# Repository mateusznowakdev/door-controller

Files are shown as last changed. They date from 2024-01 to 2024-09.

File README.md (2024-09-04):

Project description can be found on
[my website](https://mateusznowak.dev/projects/automatic-door-controller/).

User manual can be found in [docs](./docs/README.md) directory.

## Installing

(instructions for Linux)

1. Clone the repository.
    - `git clone --recurse-submodules https://github.com/mateusznowakdev/door-controller`
2. Download and flash CircuitPython 9.1.3 using the official instructions.
    - [Download](https://adafruit-circuit-python.s3.amazonaws.com/bin/raspberry_pi_pico/en_US/adafruit-circuitpython-raspberry_pi_pico-en_US-9.1.3.uf2)
3. Download mpy-cross binary to the `firmware` directory, rename it and make it
   executable.
    - [Download (amd64)](https://adafruit-circuit-python.s3.amazonaws.com/bin/mpy-cross/linux-amd64/mpy-cross-linux-amd64-9.1.3.static)
4. Build and upload the code to the CIRCUITPY drive
    - `cd firmware`
    - `./upload.sh`

## Language options

Can be changed by creating `settings.toml` file on the CIRCUITPY drive, with the
following content:

```toml
LANG = "pl"
```

Supported languages: `en`, `pl`

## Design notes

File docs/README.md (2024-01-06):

# Raspberry Pi Pico-based motor controller<br/>User manual

## 1. Overview



1. HD44780 LCD module
2. Contrast potentiometer
3. DS3231 Real Time Clock (RTC) + AT24LC32 EEPROM module
4. Raspberry Pi Pico microcontroller module
5. Button module - Left button
6. Button module - Right button
7. Button module - OK button
8. Programmable motor output signal
9. Power input / output, in the following order: 3V3, GND, 5V
10. Auto-reset jumper

### 1.1. Safe default settings

The RTC / EEPROM module is used to keep track of the current time and store user settings.

Automatic opening and closing will be temporarily disabled if the time setting is invalid. Open time settings and set the current time again. Replace the battery if the problem is not resolved.

If EEPROM contents cannot be read due to the bad checksum, the default settings will be used:

- run from 00:00 to 00:00 for 0 seconds divided by 1

### 1.2. Auto-reset feature

This device is automatically reset after failure, such as lost communication with the real time clock module. LCD and button modules are not monitored.

This feature can be disabled if access to the USB serial console is required. Remove the jumper (10.) only if requested by qualified personnel.

## 2. User menu

### 2.1. Using the button module

The three buttons of the button module are used in the user menu, and produce different results in one of two modes:

| | Left | Right | OK |
|---|---|---|---|
|  <br/> **In the menu (cursor mode)**  | Press to move the cursor left. | Press to move the cursor right. | Press to select a highlighted option. This will invoke an action, enter a sub-menu or switch to editing mode. |
|  <br/> **In the menu (editing mode)** | Press to decrease the value by 1. Press and hold to do it faster. | Press to increase the value by 1. Press and hold to do it faster. | Press to confirm the value you have entered and return to cursor mode. |

The button module may stop working temporarily in the following conditions:

- Ongoing opening or closing operation
- Hardware failure

### 2.2. Idle screen



The following information is displayed on the idle screen:

| Icon | Description |
|---|---|
| &nbsp; | Current time |
|  | Automatic reset is disabled |
|  | System time is invalid |

Press and hold the **Left** button for a few seconds to enter the main menu.

### 2.3. Main menu



The following menu options are available:

| Icon | Description |
|---|---|
|  | Show scheduled operations |
|  | Open now (single operation according to the schedule)  |
|  | Close now (single operation according to the schedule) |
|  | Change opening parameters |
|   | Change closing parameters |
|  | Change system time |
|  | Show operation history |
|  | Return to the idle screen |

"Open" and "Close" operations requested from the main menu are run synchronously at the best precision possible, which means these cannot be stopped prematurely.

### 2.4. "Preview" menu



This menu is used to list all scheduled operations and their directions. Press the **Left** or **Right** button to switch to the previous or next page, respectively, or the **OK** button to return to the main menu.

If no operations are scheduled or if the system time is invalid, the following empty screen is shown:



### 2.5. "History" menu



This menu is similar to the preview menu but is used to list important events in the past, such as:

- device status
- opening and closing operations
- changed settings

Some log entries have an extra context:

| Icon | Description |
|---|---|
|  | Single (manual) |
|  | Automatic |
|  | Measurement |

### 2.6. "Set opening" and "Set closing" menus



These menus are used to change the parameters of the scheduled opening and closing operations. The following parameters can be set:

- Time of the first operation in the series
- Time of the last operation in the series
- Total duration for all operations in series during a day
- Number of operations during a day

The following actions are also available:

| Icon | Description |
|---|---|
|  | Start automatic measurement. See "2.6.1. Measurement menu" |
|  | Save the updated settings, then return to the main menu |
|  | Ignore the updated settings, then return to the main menu  |

**Example**: This example configuration will turn on the motor for approximately 10 seconds at 08:00, 09:00, ..., 15:00, and 16:00 every
day.

It might be necessary to fine-tune these values according to the weather conditions and motor parameters.

To disable opening or closing operations, set the total duration to 0s.

#### 2.6.1. Measurement menu



This sub-menu is used to run an opening or closing operation for an unspecified amount of time, usually for measurement purposes.

The opening or closing operation is run asynchronously, which means it can be stopped by pressing the **OK** button at the cost of worse precision. The displayed value is then set as a total duration in the "Set opening" or "Set closing" menu.

### 2.7. "Set clock" menu



This menu is used to change the system time to the specified value.

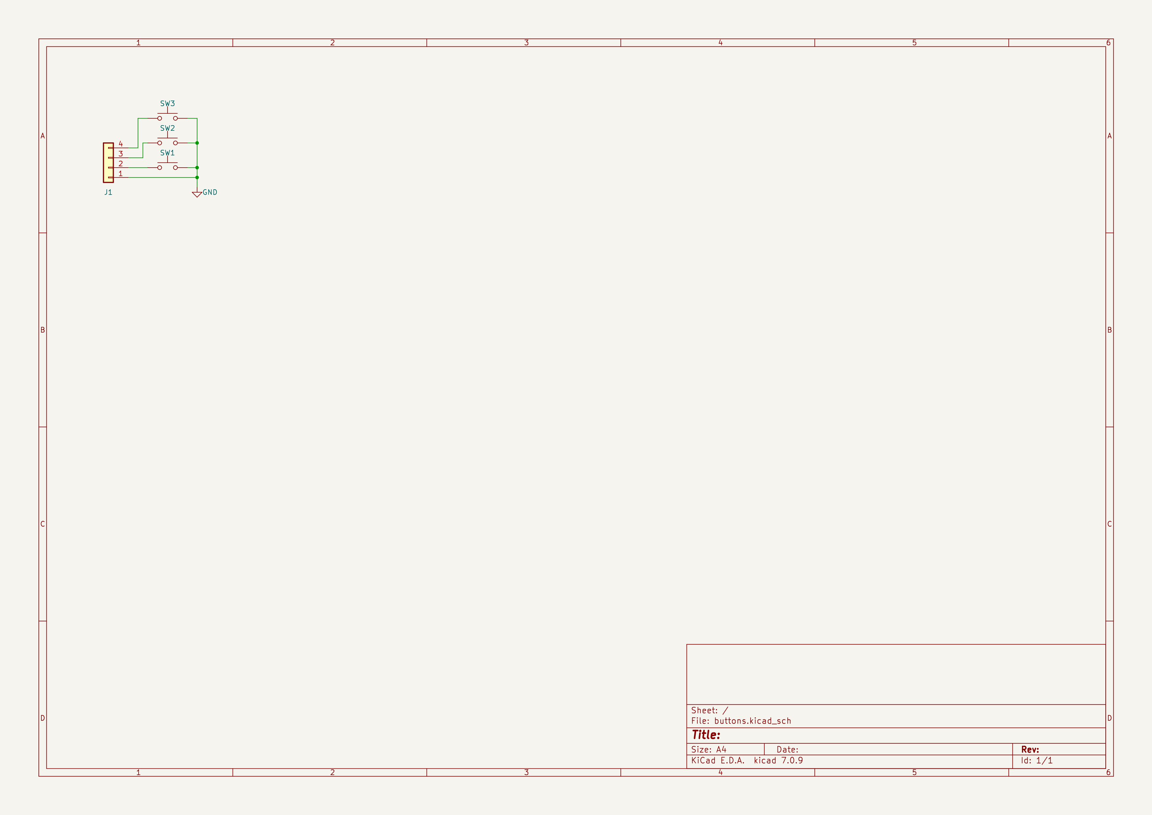
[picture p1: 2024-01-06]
hardware/buttons.png

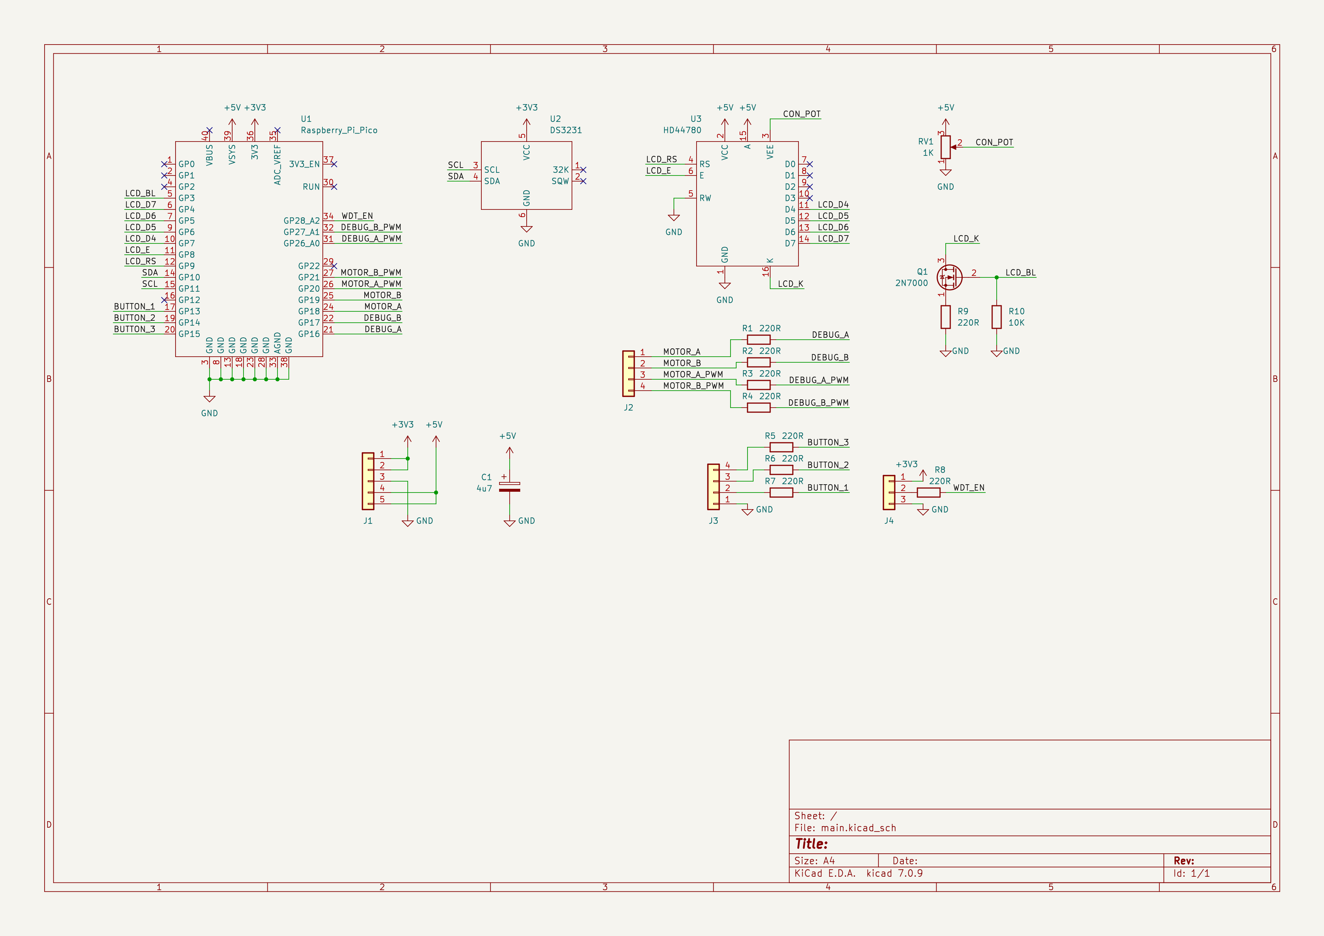
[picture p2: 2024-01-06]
hardware/main.png

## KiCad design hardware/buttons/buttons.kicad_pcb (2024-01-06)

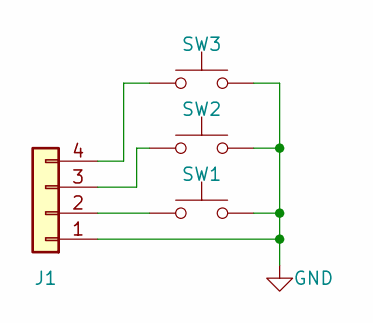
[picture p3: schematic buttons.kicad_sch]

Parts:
J1: Conn_01x04; PinSocket_1x04_P2.54mm_Vertical
SW1, SW2, SW3: SW_Push; SW_PUSH-12mm

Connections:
GND: J1.1, SW1.2, SW2.2, SW3.2
unnamed: J1.2, SW1.1
unnamed: J1.3, SW2.1
unnamed: J1.4, SW3.1

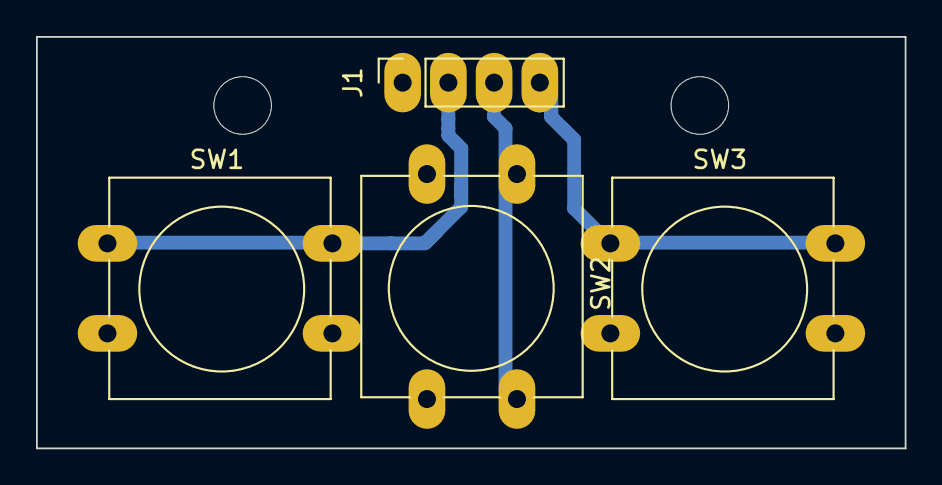
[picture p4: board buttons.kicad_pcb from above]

Board: 2 copper layers, 48.3 x 22.9 mm, 4 parts (0 on the bottom side), 4 nets.

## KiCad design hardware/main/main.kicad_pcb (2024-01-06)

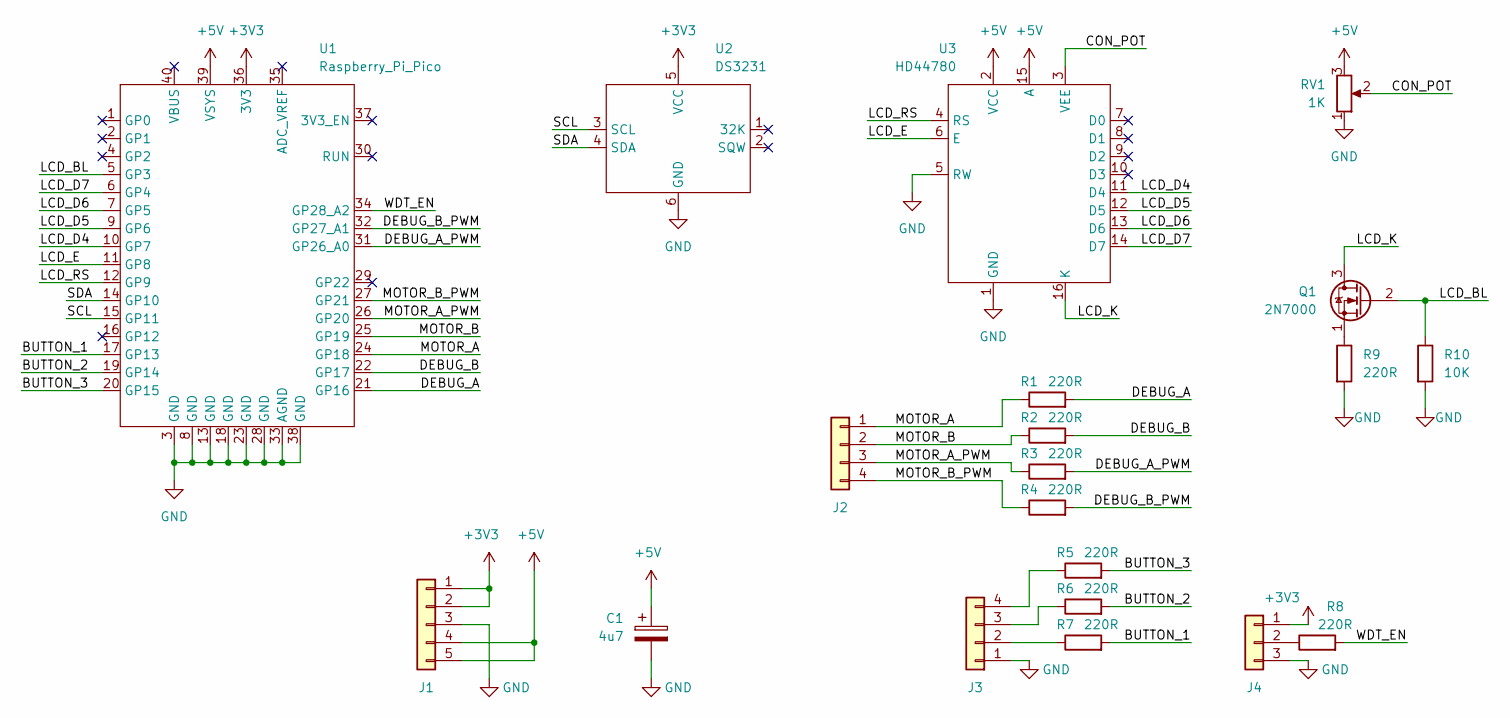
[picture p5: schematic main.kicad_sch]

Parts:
C1: 4u7; CP_Radial_D5.0mm_P2.50mm
J1: Conn_01x05; PinHeader_1x05_P2.54mm_Vertical
J2, J3: Conn_01x04; PinHeader_1x04_P2.54mm_Vertical
J4: Conn_01x03; PinHeader_1x03_P2.54mm_Vertical
Q1: 2N7000; TO-92_Inline_Wide
R1, R2, R3, R4, R5, R6, R7, R8, R9: 220R; R_Axial_DIN0207_L6.3mm_D2.5mm_P7.62mm_Horizontal
R10: 10K; R_Axial_DIN0207_L6.3mm_D2.5mm_P7.62mm_Horizontal
RV1: 1K; Potentiometer_Runtron_RM-065_Vertical
U1: Raspberry_Pi_Pico
U2: DS3231
U3: HD44780

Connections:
+3V3: J1.1, J1.2, J4.1, U1.36 (3V3), U2.5 (VCC)
+5V: C1.1, J1.4, J1.5, RV1.3, U1.39 (VSYS), U3.2 (VCC), U3.15 (A)
/BUTTON_1: R7.2, U1.17 (GP13)
/BUTTON_2: R6.2, U1.19 (GP14)
/BUTTON_3: R5.2, U1.20 (GP15)
/CON_POT: RV1.2, U3.3 (VEE)
/DEBUG_A: R1.2, U1.21 (GP16)
/DEBUG_A_PWM: R3.2, U1.31 (GP26_A0)
/DEBUG_B: R2.2, U1.22 (GP17)
/DEBUG_B_PWM: R4.2, U1.32 (GP27_A1)
/LCD_BL: Q1.2 (G), R10.1, U1.5 (GP3)
/LCD_D4: U1.10 (GP7), U3.11 (D4)
/LCD_D5: U1.9 (GP6), U3.12 (D5)
/LCD_D6: U1.7 (GP5), U3.13 (D6)
/LCD_D7: U1.6 (GP4), U3.14 (D7)
/LCD_E: U1.11 (GP8), U3.6 (E)
/LCD_K: Q1.3 (D), U3.16 (K)
/LCD_RS: U1.12 (GP9), U3.4 (RS)
/MOTOR_A: J2.1, R1.1, U1.24 (GP18)
/MOTOR_A_PWM: J2.3, R3.1, U1.26 (GP20)
/MOTOR_B: J2.2, R2.1, U1.25 (GP19)
/MOTOR_B_PWM: J2.4, R4.1, U1.27 (GP21)
/SCL: U1.15 (GP11), U2.3 (SCL)
/SDA: U1.14 (GP10), U2.4 (SDA)
/WDT_EN: R8.2, U1.34 (GP28_A2)
GND: C1.2, J1.3, J3.1, J4.3, R9.2, R10.2, RV1.1, U1.3 (GND), U1.8 (GND), U1.13 (GND), U1.18 (GND), U1.23 (GND), U1.28 (GND), U1.33 (AGND), U1.38 (GND), U2.6 (GND), U3.1 (GND), U3.5 (RW)
unnamed: J3.2, R7.1
unnamed: J3.3, R6.1
unnamed: J3.4, R5.1
unnamed: J4.2, R8.1
unnamed: Q1.1 (S), R9.1

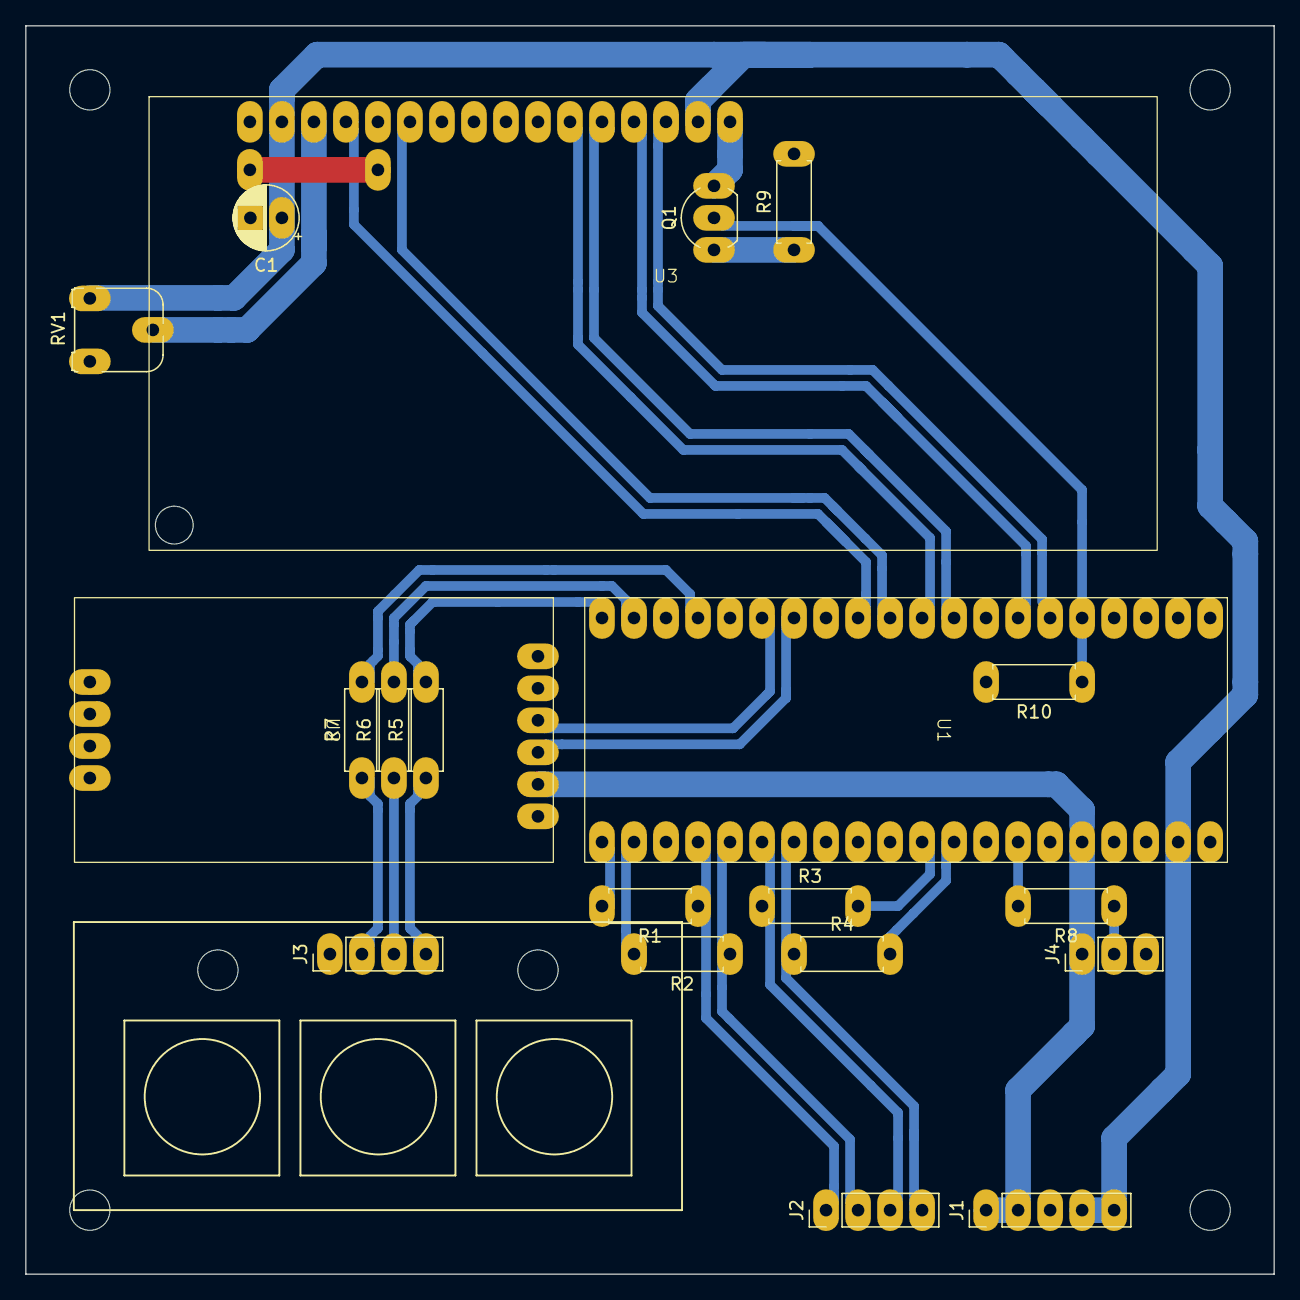
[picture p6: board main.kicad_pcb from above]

Board: 2 copper layers, 99.1 x 99.1 mm, 20 parts (0 on the bottom side), 31 nets.

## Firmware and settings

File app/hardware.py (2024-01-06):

import board
import keypad
import rtc as _rtc
import time
from busio import I2C
from digitalio import DigitalInOut, Direction, Pull
from microcontroller import watchdog
from pwmio import PWMOut
from watchdog import WatchDogMode

from adafruit_24lc32 import EEPROM_I2C
from adafruit_character_lcd.character_lcd import Character_LCD_Mono
from adafruit_ds3231 import DS3231

from app import logging
from app.classes import LogEntry
from app.utils import get_checksum, verify_checksum


class WatchDog:
    TIMEOUT = 8.0

    def __init__(self) -> None:
        self.wdt_pin = DigitalInOut(board.GP28)
        self.wdt_pin.direction = Direction.INPUT
        self.wdt_pin.pull = Pull.DOWN
        self.enabled = False

    def feed(self) -> None:
        if not self.enabled and self.wdt_pin.value is True:
            watchdog.timeout = WatchDog.TIMEOUT
            watchdog.mode = WatchDogMode.RESET
            self.enabled = True

            logging.log(logging.WATCHDOG_INIT)

        if self.enabled:
            watchdog.feed()


class Logger:
    START_ADDRESS = 1024
    END_ADDRESS = 1024 + 128

    FRAME_SIZE = 8

    END_FRAME = bytearray((255, 0, 0, 0, 0, 0, 0, 213))

    def __init__(self) -> None:
        self.address = self.START_ADDRESS

        raw = eeprom[self.START_ADDRESS : self.END_ADDRESS]
        print(f"debug raw {raw}")
        print(f"\\xff in raw: {len([x for x in raw if x == 255])}")

        for address in range(self.START_ADDRESS, self.END_ADDRESS, self.FRAME_SIZE):
            start = address - self.START_ADDRESS
            if raw[start : start + self.FRAME_SIZE] == self.END_FRAME:
                print(f"debug found {address}")
                self.address = address
                break
        else:
            print("debug not found")

    def get(self, log_id: int) -> LogEntry:
        address = self.address
        for _ in range(log_id + 1):
            address -= self.FRAME_SIZE
            if address < self.START_ADDRESS:
                address = self.END_ADDRESS - self.FRAME_SIZE

        print(f"current {self.address}")
        print(f"debug get #{log_id} from {address}")
        raw = eeprom[address : address + self.FRAME_SIZE]
        if not verify_checksum(raw):
            return LogEntry(255, logging.MESSAGES[255], 0, 0, 0)

        return LogEntry(raw[0], logging.MESSAGES[raw[0]], raw[1], raw[2], raw[3])

    def log(self, message_id: int, *args: str) -> None:
        args = list(args) + [f"(log to {self.address})"]
        logging.log(message_id, *args)

        now = time.localtime()

        raw = [message_id, now.tm_hour, now.tm_min, now.tm_sec, 0, 0, 0]
        raw.append(get_checksum(raw))

        a = self.address
        b = a + self.FRAME_SIZE
        print(f"debug writing {a}:{b} -> {raw}")
        eeprom[a:b] = bytearray(raw)

        self.address += self.FRAME_SIZE
        if self.address == self.END_ADDRESS:
            print("overlap")
            self.address = self.START_ADDRESS

        a = self.address
        b = a + self.FRAME_SIZE
        print(f"debug writing {a}:{b} -> {list(self.END_FRAME)}")
        eeprom[a:b] = self.END_FRAME


class Motor:
    # Action ID describes the first EEPROM address for its settings
    ACT_OPEN = 0
    ACT_CLOSE = 64

    def __init__(self) -> None:
        self._motor_f = DigitalInOut(board.GP18)
        self._motor_f.direction = Direction.OUTPUT

        self._motor_b = DigitalInOut(board.GP19)
        self._motor_b.direction = Direction.OUTPUT

    def sleep(self, duration: float) -> None:
        max_loop_duration = WatchDog.TIMEOUT / 2

        while duration > 0:
            wdt.feed()
            time.sleep(max_loop_duration if duration > max_loop_duration else duration)
            duration -= max_loop_duration

        wdt.feed()

    def run(self, action_id: int, duration: float) -> None:
        if action_id == Motor.ACT_OPEN:
            self.open(duration)
        elif action_id == Motor.ACT_CLOSE:
            self.close(duration)
        else:
            logger.log(logging.ACT_UNKNOWN)

    def open(self, duration: float) -> None:
        logger.log(logging.ACT_OPEN_START)

        self._motor_f.value = True
        self.sleep(duration)
        self._motor_f.value = False

        logger.log(logging.ACT_OPEN_STOP)

    def close(self, duration: float) -> None:
        logger.log(logging.ACT_CLOSE_START)

        self._motor_b.value = True
        self.sleep(duration)
        self._motor_b.value = False

        logger.log(logging.ACT_CLOSE_STOP)
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

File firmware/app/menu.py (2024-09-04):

import asyncio
import time

from app import const
from app.core import display, keys, logger, motor, rtc, scheduler, settings, wdt
from app.shared import _, chunk, clamp, format_time, log
from app.types import SettingsT


class MenuExit(Exception):
    def __init__(self, code: int = 0) -> None:
        self.code = code


class Menu:
    CURSORS = ()
    MIN_MAX_VALUES = ()

    ALT_ICONS = False

    def __init__(self) -> None:
        self.data = []
        self.pos = 0
        self.edit = False

    def get_cursor(self) -> tuple[tuple[int, int], tuple[int, int]]:
        return self.CURSORS[self.pos]

    def get_min_max_cursors(self) -> tuple[int, int]:
        return 0, len(self.CURSORS) - 1

    def get_min_max_values(self) -> tuple[int, int]:
        return self.MIN_MAX_VALUES[self.pos]

    def render(self) -> None:
        display.clear()
        display.write((0, 0), b"???")
        display.flush()

    def enter(self) -> None:
        log(f"Switching to {self.__class__.__name__}")

        if self.ALT_ICONS:
            display.set_alternate_icons()

        self.render()

    async def loop(self) -> None:
        if self.edit:
            await self.loop_edit()
        else:
            await self.loop_navi()

    async def loop_navi(self) -> None:
        await asyncio.sleep(0.05)

        key, duration = keys.get()
        if key == keys.LEFT:
            await self.loop_navi_left(duration)
        elif key == keys.RIGHT:
            await self.loop_navi_right(duration)
        elif key == keys.ENTER:
            await self.loop_navi_enter(duration)

        if key is not None:
            self.render()

    async def loop_navi_left(self, duration: float) -> None:
        _ = duration
        lo, hi = self.get_min_max_cursors()
        self.pos = clamp(self.pos - 1, lo, hi)

    async def loop_navi_right(self, duration: float) -> None:
        _ = duration
        lo, hi = self.get_min_max_cursors()
        self.pos = clamp(self.pos + 1, lo, hi)

    async def loop_navi_enter(self, duration: float) -> None:
        _ = duration
        self._enter_edit_mode()

    async def loop_edit(self) -> None:
        await asyncio.sleep(0.05)

        key, duration = keys.get()
        if key == keys.LEFT:
            self.loop_edit_left(duration)
        elif key == keys.RIGHT:
            self.loop_edit_right(duration)
        elif key == keys.ENTER:
            self.loop_edit_enter(duration)

        if key is not None:
            self.render()

    def loop_edit_left(self, duration: float) -> None:
        lo, hi = self.get_min_max_values()
        self.data[self.pos] = clamp(self.data[self.pos] - int(duration or 1), lo, hi)

    def loop_edit_right(self, duration: float) -> None:
        lo, hi = self.get_min_max_values()
        self.data[self.pos] = clamp(self.data[self.pos] + int(duration or 1), lo, hi)

    def loop_edit_enter(self, duration: float) -> None:
        _ = duration
        self._leave_edit_mode()

    def exit(self) -> None:
        if self.ALT_ICONS:
            display.set_default_icons()

    async def _enter_submenu(self, instance: "Menu") -> int:
        try:
            instance.enter()
            while True:
                await instance.loop()
        except MenuExit as e:
            instance.exit()
            self.enter()
            return e.code

    def _enter_edit_mode(self) -> None:
        display.set_backlight(display.BACKLIGHT_HIGH)
        display.set_alternate_cursor()
        self.edit = True

    def _leave_edit_mode(self) -> None:
        self.edit = False
        display.set_backlight(display.BACKLIGHT_LOW)
        display.set_default_cursor()


class IdleMenu(Menu):
    def render(self) -> None:
        now = time.localtime()

        display.clear()
        display.write((0, 0), format_time(now.tm_hour, now.tm_min, now.tm_sec))
        display.write((11, 0), b"\x04!" if not wdt.enabled else b"")
        display.write((14, 0), b"\x05!" if rtc.lost_power else b"")
        display.flush()

    async def loop_navi(self) -> None:
        await super().loop_navi()

        # time should be refreshed even if there is no input
        self.render()

    async def loop_navi_left(self, duration: float) -> None:
        if duration > 3.0:
            await self._enter_submenu(MainMenu())

    async def loop_navi_right(self, duration: float) -> None:
        return

    async def loop_navi_enter(self, duration: float) -> None:
        return


class MainMenu(Menu):
    CURSORS = (
        ((0, 0), (2, 0)),
        ((2, 0), (4, 0)),
        ((4, 0), (6, 0)),
        ((6, 0), (8, 0)),
        ((8, 0), (10, 0)),
        ((10, 0), (12, 0)),
        ((12, 0), (14, 0)),
        ((14, 0), (16, 0)),
    )

    LABELS = (
        _(const.MENU_PREVIEW),
        _(const.MENU_OPEN),
        _(const.MENU_CLOSE),
        _(const.MENU_SET_OPEN),
        _(const.MENU_SET_CLOSE),
        _(const.MENU_SET_TIME),
        _(const.MENU_HISTORY),
        _(const.MENU_RETURN),
    )

    ID_PREVIEW = 0
    ID_OPEN = 1
    ID_CLOSE = 2
    ID_SET_OPEN = 3
    ID_SET_CLOSE = 4
    ID_SET_TIME = 5
    ID_HISTORY = 6
    ID_RETURN = 7

    def get_label(self) -> bytes:
        return self.LABELS[self.pos].encode()

    def enter(self) -> None:
        super().enter()
        display.set_backlight(display.BACKLIGHT_LOW)

    def render(self) -> None:
        (cax, cay), (cbx, cby) = self.get_cursor()
        label = self.get_label()

        # scroll menu to the left
        offset = 0 if self.pos < 4 else -1

        display.clear()
        display.write((1 + offset, 0), b"\x05 \x00 \x01 \x02 \x03 \x04 \xD0 \x7F")
        display.write((cax + offset, cay), b"\x06")
        display.write((cbx + offset, cby), b"\x07")
        display.write((1, 1), label)
        display.flush()

    async def loop_navi_enter(self, duration: float) -> None:
        if self.pos == self.ID_PREVIEW:
            await self._enter_submenu(PreviewMenu())
        elif self.pos == self.ID_SET_OPEN:
            await self._enter_submenu(MotorMenu(motor.ACT_OPEN))
        elif self.pos == self.ID_SET_CLOSE:
            await self._enter_submenu(MotorMenu(motor.ACT_CLOSE))
        elif self.pos == self.ID_SET_TIME:
            await self._enter_submenu(SystemMenu())
        elif self.pos == self.ID_HISTORY:
            await self._enter_submenu(HistoryMenu())
        elif self.pos == self.ID_RETURN:
            raise MenuExit()
        else:
            await super().loop_navi_enter(duration)

    async def loop_edit(self) -> None:
        reason = motor.REASON_ONESHOT

        if self.pos == self.ID_OPEN:
            motor.open(reason, settings.load(motor.ACT_OPEN).duration_single)
            self._leave_edit_mode()
        elif self.pos == self.ID_CLOSE:
            motor.close(reason, settings.load(motor.ACT_CLOSE).duration_single)
            self._leave_edit_mode()
        else:
            await super().loop_navi()
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

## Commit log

2024-01-06 Use buttons to change cursor position
2024-01-06 Switch between two menu screens
2024-01-06 Change display brightness when switching menu screens
2024-01-06 Display current time on the idle screen
2024-01-06 Check CircuitPython version before upload
2024-01-06 Create fake motor class
2024-01-06 Encapsulate switching between edit and navigation modes
2024-01-06 Create valid times list for sample schedule
2024-01-06 Change base checksum value to avoid false negatives
    [utils.py]
2024-01-06 Rename occurrences of 'forward' and 'backward' in motor code
2024-01-06 Explicitly define pull mode for watchdog pin
2024-01-06 Display current temperature
2024-01-06 Reset max EEPROM size to the default value
    [hardware.py]
2024-01-06 Store current time in a log entry
2024-01-06 Store board init log entry in the EEPROM
2024-01-06 Reset to factory settings if header mismatched
    [const.py, core.py]
2024-01-06 Update CircuitPython to 8.2.9
2024-01-06 Add code for real motor driver
2024-01-06 Add cancel button in setting menus
2024-01-06 Remove redundant Motor.run() function
2024-01-06 Add asynchronous motor functions
2024-01-06 Stop motor if parent has cancelled the async task
2024-01-06 Prevent controlling motor from multiple sources at the same time
    [core.py]
2024-01-06 Add separate log IDs for auto, manual and measure motor actions
2024-01-06 Use consistent format of motor actions reason
2024-01-06 Fix invalid action IDs
    [const.py]
2024-01-06 Add hardware files
    [buttons.kicad_pcb, buttons.kicad_sch, main.kicad_pcb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]
2024-01-06 Add KiCAD files to .gitignore
2024-04-12 Update to CircuitPython 9.0.3
2024-09-04 Update to CircuitPython 9.1.3
